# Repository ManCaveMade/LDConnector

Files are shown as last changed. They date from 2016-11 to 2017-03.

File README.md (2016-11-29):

## LDConnector
Copyright Mitchell A. Cox (mitch@enox.co.za)

If you use this design, please acknowledge me in any resulting publications.

### Note

v1.0 doesn't seem to work with high frequency. This is probably because the RF is connected to the case, which sucks.
v2.0 is redesigned to work with a bias driver that is on the GND side of the LD. This is "normal".
 
Designed with Eagle 7.7

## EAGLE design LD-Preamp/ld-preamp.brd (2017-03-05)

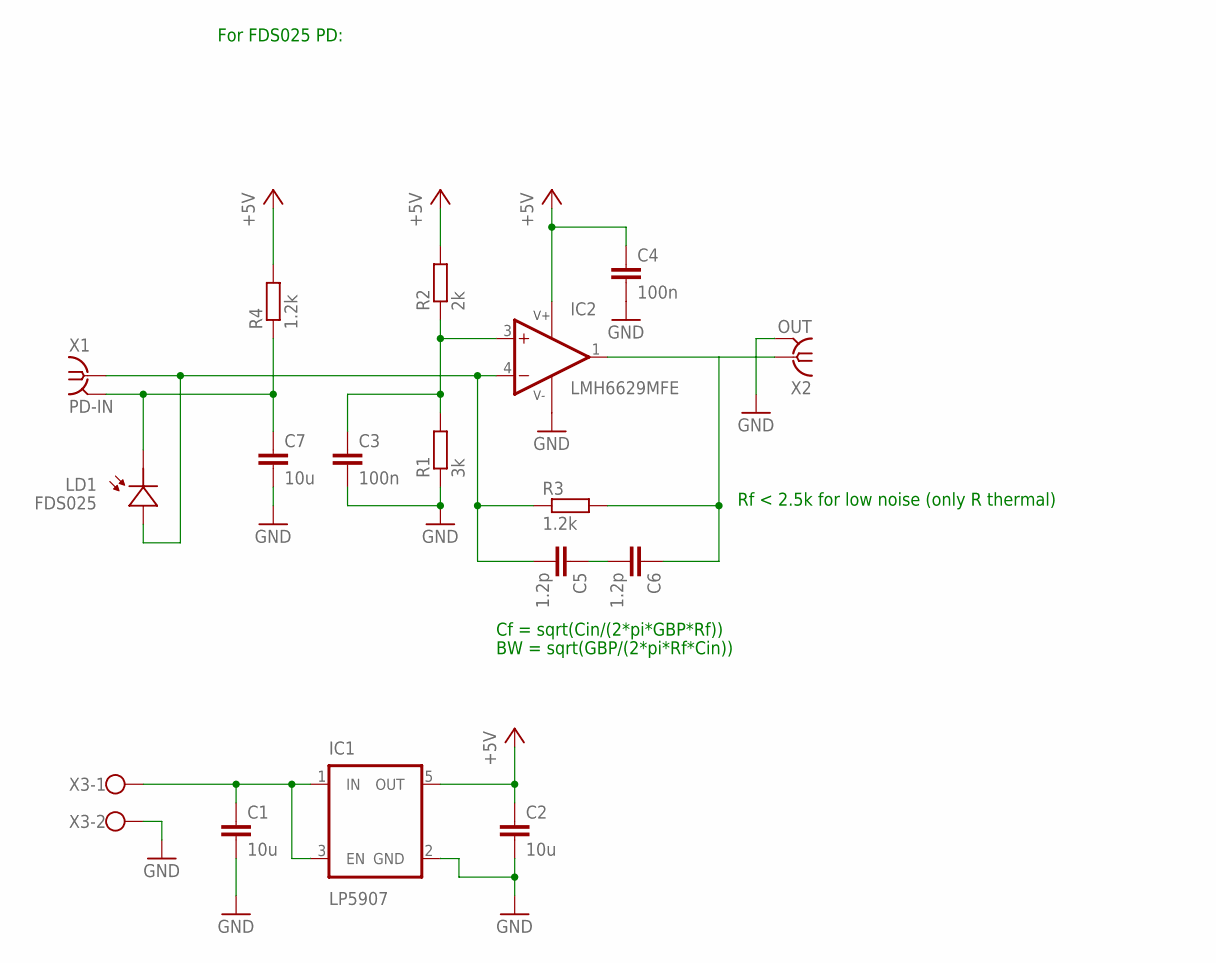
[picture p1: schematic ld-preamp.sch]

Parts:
C1, C2, C7: 10u; C0805
C3, C4: 100n; C0603
C5, C6: 1.2p; C0603
IC1: LP5907; SOT23-5
IC2: LMH6629MFE; SOT23-5
LD1: FDS025; PD-TO46-EDGE
R1: 3k; R0603
R2: 2k; R0603
R3, R4: 1.2k; R0603
X1: PD-IN; J502-ND-142-0711-821/826
X2: OUT; J502-ND-142-0711-821/826
X3: W237-102

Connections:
+5V: C2.1, C4.1, IC1.5 (OUT), IC2.5 (V+), R2.2, R4.2
GND: C1.2, C2.2, C3.2, C4.2, C7.2, IC1.2 (GND), IC2.2 (V-), R1.1, X2.G@1 (2), X2.G@2 (2), X2.G@3 (2), X2.G@4 (2), X3.2
unnamed: C1.1, IC1.1 (IN), IC1.3 (EN), X3.1
unnamed: C3.1, IC2.3 (+IN), R1.2, R2.1
unnamed: C5.2, IC2.4 (-IN), LD1.3 (PDA), R3.1, X1.1
unnamed: C5.1, C6.2
unnamed: C6.1, IC2.1 (OUT), R3.2, X2.1
unnamed: C7.1, LD1.1 (PDC), R4.1, X1.G@1 (2), X1.G@2 (2), X1.G@3 (2), X1.G@4 (2)

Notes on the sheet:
Cf = sqrt(Cin/(2*pi*GBP*Rf))
BW = sqrt(GBP/(2*pi*Rf*Cin))
Rf < 2.5k for low noise (only R thermal)
For FDS025 PD:

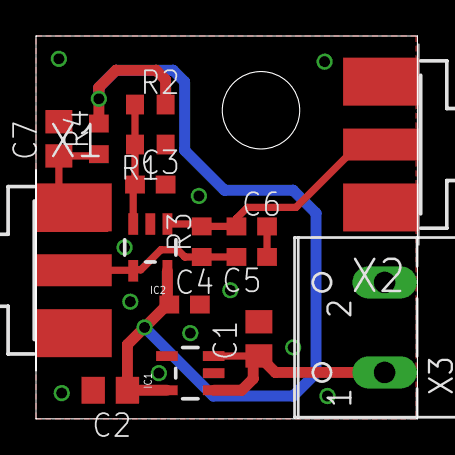
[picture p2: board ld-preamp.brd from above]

Board: 2 copper layers, 21.2 x 21.3 mm, 17 parts (0 on the bottom side), 8 nets.

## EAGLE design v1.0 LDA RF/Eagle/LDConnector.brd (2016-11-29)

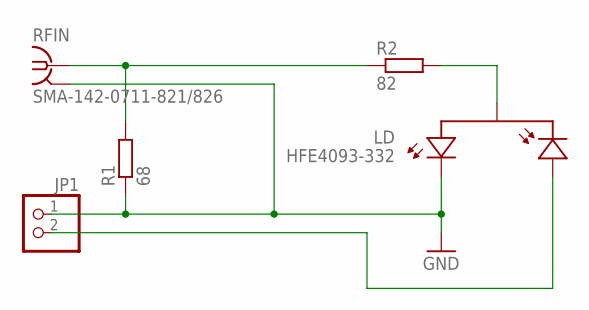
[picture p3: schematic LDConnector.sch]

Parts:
JP1: PINHD-1X2/90; 1X02/90
LD: HFE4093-332; HFE4093-332-EDGE
R1: 68; R0603
R2: 82; R0603
RFIN: SMA-142-0711-821/826; J502-ND-142-0711-821/826

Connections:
GND: JP1.1, LD.1-LD-CATHODE (LDC), R1.1, RFIN.G@1 (2), RFIN.G@2 (2), RFIN.G@3 (2), RFIN.G@4 (2)
unnamed: LD.2-PD-CATHODE-LD-ANO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 (LDA-PDC), R2.2
unnamed: R1.2, R2.1, RFIN.1
unnamed: JP1.2, LD.3-PD-ANODE (PDA)

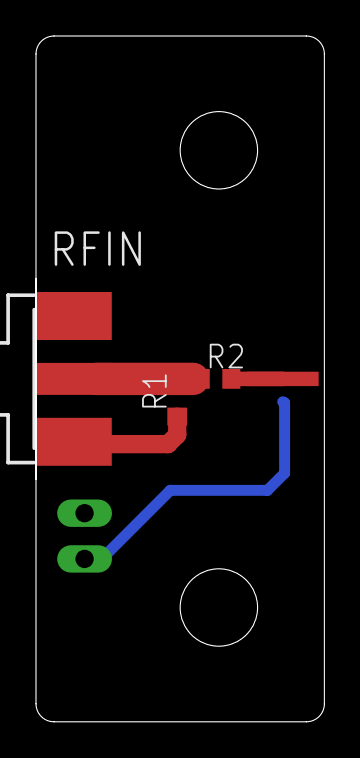
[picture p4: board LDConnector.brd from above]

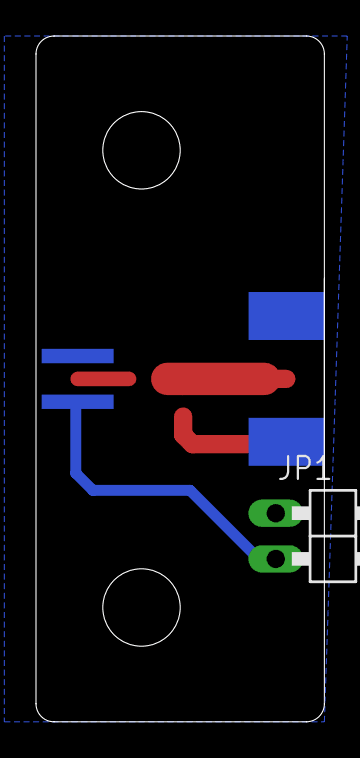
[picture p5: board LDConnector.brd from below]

Board: 2 copper layers, 16.0 x 38.1 mm, 5 parts (2 on the bottom side), 4 nets.

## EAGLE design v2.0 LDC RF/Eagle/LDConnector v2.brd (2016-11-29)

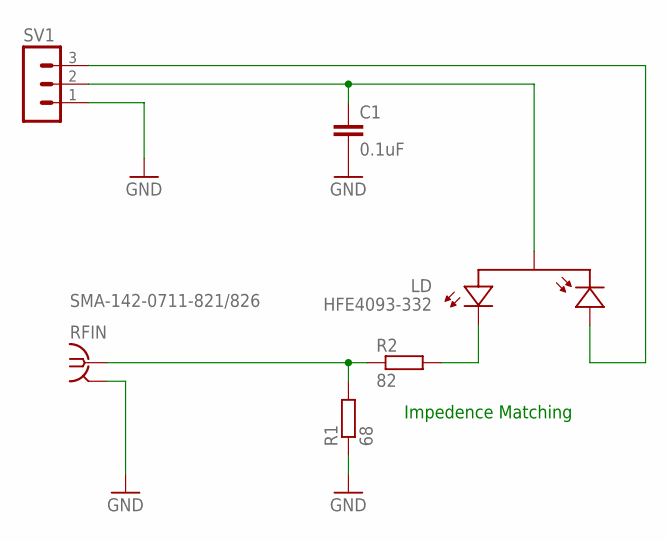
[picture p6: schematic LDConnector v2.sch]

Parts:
C1: 0.1uF; C0603
LD: HFE4093-332; HFE4093-332-EDGE
R1: 68; R0603
R2: 82; R0603
RFIN: SMA-142-0711-821/826; J502-ND-142-0711-821/826
SV1: MA03-1

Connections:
GND: C1.2, R1.1, RFIN.G@1 (2), RFIN.G@2 (2), RFIN.G@3 (2), RFIN.G@4 (2), SV1.1
unnamed: C1.1, LD.2-PD-CATHODE-LD-ANO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 (LDA-PDC), SV1.2
unnamed: LD.1-LD-CATHODE (LDC), R2.2
unnamed: R1.2, R2.1, RFIN.1
unnamed: LD.3-PD-ANODE (PDA), SV1.3

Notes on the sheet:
Impedence Matching

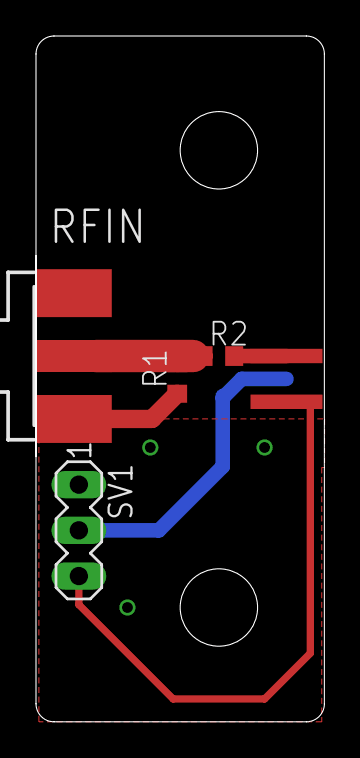
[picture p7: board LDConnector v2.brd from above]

Board: 2 copper layers, 16.0 x 38.1 mm, 6 parts (1 on the bottom side), 5 nets.

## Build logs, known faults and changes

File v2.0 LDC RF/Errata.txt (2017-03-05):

The LD pin 1 and 3 are swapped around :( Need to mount the LD upside down now! Shit!

Silkscreen errors.

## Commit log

2016-11-29 First commit of everything.
    [LDConnector v2.brd, LDConnector v2.sch, LDConnector.brd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]
2017-03-05 started work on a high bandwidth, low noise preamp
    [ld-preamp.brd, ld-preamp.sch]
